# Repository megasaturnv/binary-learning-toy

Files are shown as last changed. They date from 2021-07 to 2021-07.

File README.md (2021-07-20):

# binary-learning-toy
A toy to help children and adults learn binary

### Pin connections
```
1	Switch128
0	Switch64
				
2	Switch32	A3	SegmentF
3	Switch16	A2	SegmentE
4	Switch8		A1	SegmentD
5	Switch4		A0	SegmentC
6	Switch2		13	SegmentB
7	Switch1		12	SegmentA
8	Digit1		11	Digit4
9	Digit2		10	Digit3

A4	SegmentG
A5	SegmentDP
A6	Switch Signed
A7	Switch Dec/Hex

binary switches		8
lower switches		2
digit pins		4
segment pins		8

total			22
```

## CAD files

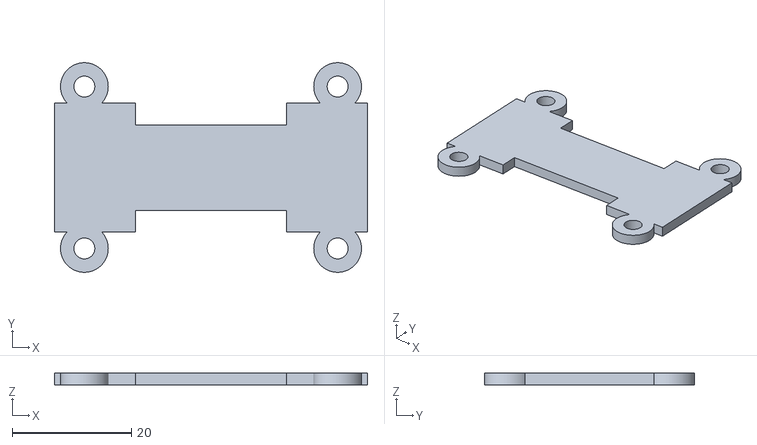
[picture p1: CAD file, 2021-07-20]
OpenSCAD/Binary_Display_Toy_DisplayLid.stl
52.4 x 35.1 x 2.00

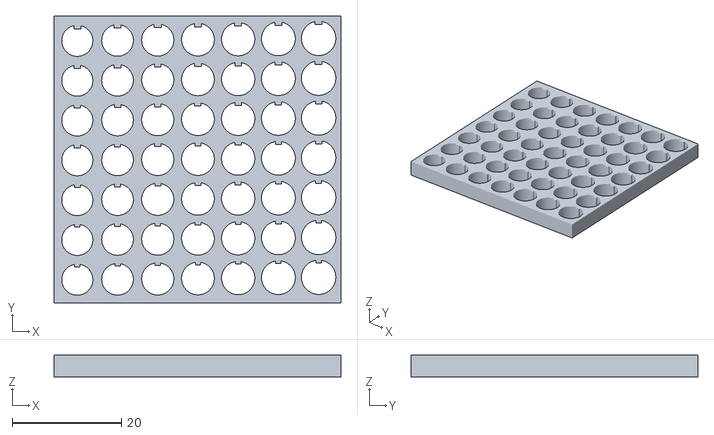
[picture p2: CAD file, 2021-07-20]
Testing/keyedSwitchHolesTest.stl
52.6 x 52.6 x 4.00

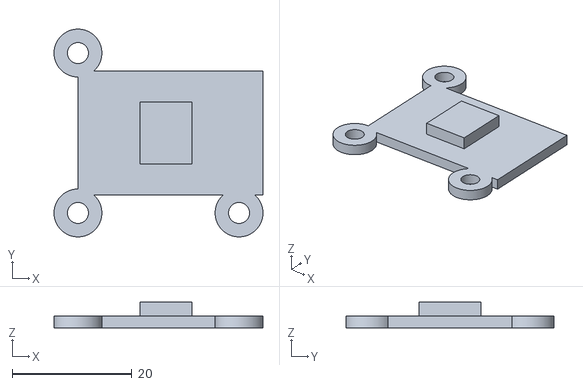
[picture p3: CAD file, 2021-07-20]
OpenSCAD/Binary_Display_Toy_ArduinoLid.stl
34.9 x 34.7 x 4.33

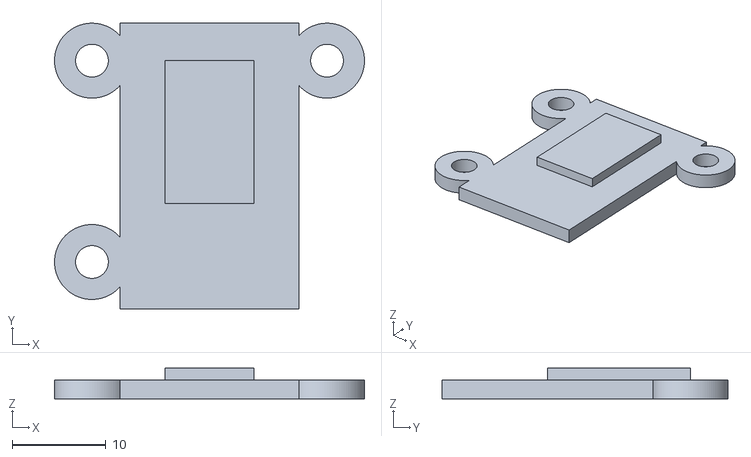
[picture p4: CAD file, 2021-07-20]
OpenSCAD/Binary_Display_Toy_BoxTP4056Lid.stl
33.1 x 30.5 x 3.30

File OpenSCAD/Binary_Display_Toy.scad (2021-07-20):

//Counting_Toy.scad by MegaSaturnv 2021-04-02
 
//TODO:
// * Replace signed and unsigned lines with variables and calculations

/////////////////////////////
// Customizable Parameters //
/////////////////////////////
/* [Basic] */
ROUNDED_EDGES      = true;

RENDER_BOX_BASE    = true;
RENDER_BOX_LID     = true;
RENDER_DISPLAY_LID = true;
RENDER_ARDUINO_LID = true;
RENDER_TP4056_LID  = true;

CURRENT_DATE = "2021-04-11";

BOX_X             = 150;
BOX_Y             = 71;
BOX_Z             = 40;
BOX_LID_Z         = 4;
BOX_LID_TOLERANCE = 0.4;
BOX_THICKNESS     = 2;

BOX_SCREW_MOUNT_DIAMETER      = 12;
BOX_SCREW_MOUNT_HOLE_DIAMETER = 3.2;
BOX_SCREW_MOUNT_HOLE_DEPTH    = 26;
BOX_SCREW_MOUNT_POSITION      = 6;

TEXT_SIZE         = 5;
TEXT_DEPTH        = 0.4;
TEXT_FONT         = "Liberation Sans:style=Bold";
TEXT_UPPER_OFFSET = 3;
TEXT_LOWER_OFFSET = 7;

DISPLAY_WIDTH      = 50.4;
DISPLAY_LENGTH     = 19.1;
DISPLAY_THICKNESS  = 8;
DISPLAY_TOP_MARGIN = 10;

SWITCH_HOLE_DIAMETER = 6.2;
SWITCH_HOLE_KEY_SIZE = 1.2;
SWITCH_POST_DIAMETER = 13;
SWITCH_POST_HEIGHT   = 7-BOX_THICKNESS;

UPPER_SWITCH_DISTANCE_BETWEEN = 9.5;
UPPER_SWITCH_QUANTITY         = 8;
UPPER_SWITCH_Y                = 50;
UPPER_SWITCH_TEXT_2           = ["1", "2", "4", "8", "16", "32", "64", "+/-"];

LOWER_SWITCH_Y = 15;
LOWER_SWITCH_X = 43;

LINES_WIDTH = 1;
LINES_DEPTH = 0.4;

18650_HOLDER_HEIGHT         = 30;
18650_TRIANGLE_EXTRA_HEIGHT = 2;
18650_HEIGHT                = 65;
18650_DIAMETER              = 18.3;
18650_SHELF_SIZE            = 8;

CIRCUITBOARDS_SCREW_MOUNT_DIAMETER      = 8; //4.7
CIRCUITBOARDS_SCREW_MOUNT_HOLE_DIAMETER = 2.5;
CIRCUITBOARDS_SCREW_MOUNT_HOLE_DEPTH    = 6;
CIRCUITBOARDS_WALL_THICKNESS            = 1;
CIRCUITBOARDS_LID_THICKNESS             = 2;

ON_OFF_SWITCH_HOLE_WIDTH  = 19.1;
ON_OFF_SWITCH_HOLE_LENGTH = 12.6;
ON_OFF_SWITCH_POS_X       = 17.4;
ON_OFF_SWITCH_POS_Z       = 20;

TP4056_WIDTH           = 17.1;
TP4056_LENGTH          = 28.5;
TP4056_THICKNESS       = 4.6;
TP4056_MOUNT_HEIGHT    = 5;
TP4056_USB_HOLE_HEIGHT = 3.0;
TP4056_USB_HOLE_WIDTH  = 8.5;
TP4056_CHARGING_LEDS_CUTOUT_POS_X  = 14.4;
TP4056_CHARGING_LEDS_CUTOUT_POS_Y  = 5.6;
TP4056_CHARGING_LEDS_CUTOUT_WIDTH  = 2;
TP4056_CHARGING_LEDS_CUTOUT_LENGTH = 6;

ARDUINO_PRO_MINI_WIDTH        = 18.7;
ARDUINO_PRO_MINI_LENGTH       = 33.9;
ARDUINO_PRO_MINI_THICKNESS    = 3.3;
ARDUINO_PRO_MINI_SCREW_HEIGHT = 2.5;

/* [Advanced] */
//Use $fn = 24 if it's a preview. $fn = 96 for the render. Increase 96 to produce a smoother curve.
$fn = $preview ? 24 : 96;


/////////////
// Modules //
/////////////
// https://www.thingiverse.com/thing:58478
// Rounded primitives for openscad
// (c) 2013 Wouter Robers 
module rcube(Size=[20,20,20],b=2)
{hull(){for(x=[-(Size[0]/2-b),(Size[0]/2-b)]){for(y=[-(Size[1]/2-b),(Size[1]/2-b)]){for(z=[-(Size[2]/2-b),(Size[2]/2-b)]){ translate([x,y,z]) sphere(b);}}}}}

module rcubeSlice(Size=[20,20,20],b=2) {
	translate([0, 0, -b])
	difference() {
		rcube([Size[0], Size[1], Size[2]+b*2], b);
	}
	cube([Size[0], Size[1], b]);
	translate([0, 0, Size[2]]) cube([Size[0], Size[1], b]);	
}

module roundedCorner(sideLength=8, thickness=2, cylinderCenter=false) {
	difference() {
		cube([sideLength, sideLength, thickness]);
		if (cylinderCenter) { //Cylinder cutout is in the centre
			translate([0, 0, -0.01]) cylinder(r=sideLength, h=thickness+0.02);
		} else { //Corner of the object is in the centre
			translate([sideLength, sideLength, -0.01]) cylinder(r=sideLength, h=thickness+0.02);
		}
	}
}

module drawAvatar(pxSize=2, thickness=2, center=true) {
    avatar = [
    " X X ",
    "XX XX",
    " XXX ",
    "  X  ",
    "X X X"];
    for (i = [0 : len(avatar)-1], j = [0 : len(avatar[i])-1]) {
        if (avatar[i][j] == "X") {
			if (center)	{
				translate([-(len(avatar)*pxSize)/2, -(len(avatar[0])*pxSize)/2, 0])
				translate([i*pxSize, j*pxSize, 0])
				cube([pxSize, pxSize, thickness]);
			} else {
				translate([i*pxSize, j*pxSize, 0])
				cube([pxSize, pxSize, thickness]);
			}
        }
    }
}

module switchHolePostOld(holeDiameter=6, postDiameter=12, keySize=1, height=2) {
	difference() {
		cylinder(d=postDiameter, h=height);
		difference() {
			translate([0, 0, -0.01]) cylinder(d=holeDiameter, h=height+0.02);
			translate([keySize/-2, holeDiameter/2 - keySize/2, -0.01]) cube([keySize, keySize, height+0.02]);
		}
	}
}
module switchHolePost(holeDiameter=6, postDiameter=12, keySize=1, height=2, justHole=false) {
	if (justHole) {
		difference() {
			cylinder(d=holeDiameter, h=height);
			translate([keySize/-2, holeDiameter/2 - keySize/2, -0.01]) cube([keySize, keySize, height+0.02]);
		}
	} else {
		difference() {
			cylinder(d=postDiameter, h=height);
			translate([0, 0, -0.01]) cylinder(d=holeDiameter, h=height+0.02);
		}
		translate([keySize/-2, holeDiameter/2 - keySize/2, 0]) cube([keySize, keySize, height]);
	}
}

module screwMountingPosts(width=50, length=30, screwHoleHeight=5, screwHoleOuterDiameter=6, screwHoleInnerDiameter=3, screwHoleInnerDepth=3, center=true, justHole=false) {
	if (center) {
		for (i=[-1,1], j=[-1,1]) {
			translate([i*(width/2), j*(length/2), 0]) difference() {
				if (!justHole) cylinder(d=screwHoleOuterDiameter, h=screwHoleHeight);
				translate([0,0,screwHoleHeight-screwHoleInnerDepth]) cylinder(d=screwHoleInnerDiameter, h=screwHoleInnerDepth+0.01);
			}
		}
	} else {
		for (i=[0,2], j=[0,2]) {
			translate([i*(width/2), j*(length/2), 0]) difference() {
				if (!justHole) cylinder(d=screwHoleOuterDiameter, h=screwHoleHeight);
				translate([0,0,screwHoleHeight-screwHoleInnerDepth]) cylinder(d=screwHoleInnerDiameter, h=screwHoleInnerDepth+0.01);
			}
		}
	}
}

module screwMount(height, diameter, holeDepth, holeDiameter, JustHole=false) {
	difference() {
		if (!JustHole) {
			cylinder(h=height, r=diameter/2);
		}
		translate([0, 0, height-holeDepth]) cylinder(h=holeDepth+0.01, r=holeDiameter/2);
	}
}

module triangle(XLength=5, YLength=8, thickness=2) {
    linear_extrude(height=thickness)
    {
        polygon(points=[[0,0],[XLength,0],[0,YLength]], paths=[[0,1,2]]);
    }
}

module holder18650(height=25, center=false, diameter18650=18, height18650=65, triangleExtraHeight=3.5) {
	if (center) {
		translate([-height18650/2, 0, 0])
		difference() {
			union() {
				//Main Block
				translate([-3, -diameter18650, -height]) cube([height18650+6, diameter18650 + 2, height-diameter18650/2]);
				//End caps
				//translate([-3, -diameter18650, -diameter18650]) cube([2, diameter18650, diameter18650]);
				//translate([height18650 + 1, -diameter18650, -diameter18650]) cube([2, diameter18650, diameter18650]);
			}
			translate([-1, -diameter18650/2, -diameter18650/2]) rotate([0, 90, 0]) cylinder(d=diameter18650, h=height18650+2);
			translate([height18650 + 3 + 0.01, -diameter18650-0.01, -height-0.01]) rotate([0, 270, 0]) triangle(height - diameter18650 + triangleExtraHeight + 0.01, diameter18650 + 0.01, height18650 + 6 + 0.02);
			translate([18650_SHELF_SIZE, -diameter18650-0.01, -height-0.01]) cube([height18650 - 2*18650_SHELF_SIZE, diameter18650+2.02, height+0.01]);
		}
	} else {
		translate([3, 0, 0])
		difference() {
			union() {
				//Main Block
				translate([-3, -diameter18650, -height]) cube([height18650+6, diameter18650 + 2, height-diameter18650/2]);
				//End caps
				//translate([-3, -diameter18650, -diameter18650]) cube([2, diameter18650, diameter18650]);
				//translate([height18650 + 1, -diameter18650, -diameter18650]) cube([2, diameter18650, diameter18650]);
			}
			translate([-1, -diameter18650/2, -diameter18650/2]) rotate([0, 90, 0]) cylinder(d=diameter18650, h=height18650+2);
			translate([height18650 + 3 + 0.01, -diameter18650-0.01, -height-0.01]) rotate([0, 270, 0]) triangle(height - diameter18650 + triangleExtraHeight + 0.01, diameter18650 + 0.01, height18650 + 6 + 0.02);
			translate([4, -diameter18650-0.01, -height-0.01]) cube([height18650-8 , diameter18650+2.02, height+0.01]);
		}
	}
}

module holder18650UpperHalf(center=false, diameter18650=18, height18650=65) {
	if (center) {
		translate([-height18650/2, 0, 0])
		difference() {
			translate([0, -diameter18650, -diameter18650/2]) cube([height18650, diameter18650, diameter18650/2]);
			translate([-0.01, -diameter18650/2, -diameter18650/2]) rotate([0, 90, 0]) cylinder(d=diameter18650, h=height18650+0.02);
		}
	} else {
		translate([3, 0, 0])
		difference() {
			translate([0, -diameter18650, -diameter18650/2]) cube([height18650, diameter18650, diameter18650/2]);
			translate([-0.01, -diameter18650/2, -diameter18650/2]) rotate([0, 90, 0]) cylinder(d=diameter18650, h=height18650+0.02);
		}
	}
}
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

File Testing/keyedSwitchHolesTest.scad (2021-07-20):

// By MegaSaturnv

/////////////////////////////
// Customizable Parameters //
/////////////////////////////
/* [Basic] */
HOLE_HEIGHT = 4;
HOLE_X_SPACING = 7.3;
HOLE_Y_SPACING = 7.3;

switchHolesSizes = [5.7,  5.8,  5.9,  6.0,  6.1,  6.2,  6.3];  // 6.1 is best
keySizes         = [1.00, 1.05, 1.10, 1.15, 1.20, 1.25, 1.30]; // 1.2 is best

/* [Advanced] */
//Use $fn = 24 if it's a preview. $fn = 96 for the render. Increase 96 to produce a smoother curve.
$fn = $preview ? 24 : 96;

////////////////
// Main Model //
////////////////
difference() {
	cube([len(switchHolesSizes) * HOLE_X_SPACING + 0.25*switchHolesSizes[round(len(switchHolesSizes)/2)], len(keySizes) * HOLE_Y_SPACING + 0.25*switchHolesSizes[round(len(switchHolesSizes)/2)], HOLE_HEIGHT]);
	for (diameterInc = [0:len(switchHolesSizes)-1], keyInc = [0:len(keySizes)-1]) {
		translate([diameterInc * HOLE_X_SPACING + 0.75*switchHolesSizes[diameterInc], keyInc * HOLE_Y_SPACING + 0.75*switchHolesSizes[diameterInc], -0.01]) difference() {
			cylinder(d=switchHolesSizes[diameterInc], h=HOLE_HEIGHT+0.02);
			translate([keySizes[keyInc]/-2, switchHolesSizes[diameterInc]/2 - keySizes[keyInc]/2, 0]) cube([keySizes[keyInc], keySizes[keyInc], HOLE_HEIGHT+0.02]);
		}
	}
}

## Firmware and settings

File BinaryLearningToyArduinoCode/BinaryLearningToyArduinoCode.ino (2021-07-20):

// TODO:
// Fix bug with 16-bit mode showing negative numbers
// Write code to make it show battery level in %
// Show battery level in % on startup
// Add a secret which shows the last 4 digits of millis()
// Add a secret for a simple AND/OR calculator. A change of signed switch saves the first number and selects enter next number. Position of signed switch selects AND/OR (could show AND/OR on screen until a bit is changed). Answer is displayed after toggling DEC/HEX, in either DEC/HEX depending on switch pos
// check values of SEG_A, SEG_B, SEG_C etc. Probably just 1,2,4,8...
// Replace if else if else if else if with switch case

////////////////////
// Basic Settings //
////////////////////
// Use 'true' if you'd like to keep any leading zeros
#define LEADING_ZEROS false

// Set brightness of display between 0 and 100
#define BRIGHTNESS 100


//////////////////
// Defined Pins //
//////////////////
#define SWITCH_128 1
#define SWITCH_64  0
#define SWITCH_32  2
#define SWITCH_16  3
#define SWITCH_8   4
#define SWITCH_4   5
#define SWITCH_2   6
#define SWITCH_1   7

#define DIGIT_1    8
#define DIGIT_2    9
#define DIGIT_3    10
#define DIGIT_4    11

#define SEGMENT_A  12
#define SEGMENT_B  13
#define SEGMENT_C  14 // A0
#define SEGMENT_D  15 // A1
#define SEGMENT_E  16 // A2
#define SEGMENT_F  17 // A3
#define SEGMENT_G  18 // A4
#define SEGMENT_DP 19 // A5

#define SWITCH_SIGNED 20  // A6
#define SWITCH_DEC_HEX 21 // A7




//////////////////////
// Global Variables //
//////////////////////
#include <SevSeg.h>
SevSeg sevseg; // Instantiate a seven segment object

byte switchesPins[] = {SWITCH_128, SWITCH_64, SWITCH_32, SWITCH_16, SWITCH_8, SWITCH_4, SWITCH_2, SWITCH_1};
byte digitPins[] = {DIGIT_1, DIGIT_2, DIGIT_3, DIGIT_4};
byte segmentPins[] = {SEGMENT_A, SEGMENT_B, SEGMENT_C, SEGMENT_D, SEGMENT_E, SEGMENT_F, SEGMENT_G, SEGMENT_DP};

String customText = " custom ";

bool slowmode = false;

///////////////
// Functions //
///////////////
int readSwitches() {
  uint8_t number = 0;

  // Read in the bits
  for (byte i = 0; i < sizeof(switchesPins); i++) {
    bitWrite(number, 7 - i, !digitalRead(switchesPins[i]));
  }

  if (digitalReadA6A7(SWITCH_SIGNED)) {
    // Read in 8 switches as an unsigned binary number
    return int(number);
  } else {
    // Convert unsigned number to a signed number
    return int(int8_t(number));
  }

}

byte readSwitchesUnsigned() {
  byte number = 0;

  // Read in the bits
  for (byte i = 0; i < sizeof(switchesPins); i++) {
    bitWrite(number, 7 - i, !digitalRead(switchesPins[i]));
  }
  return number;
}

//byte segmentStatusByte = 0;
//for (int i = 0; i < 8; i++) {
//  segmentStatusByte += (segmentStatus[i] << (7 - i));
//}

byte readSwitchesByte() {
  byte number = 0;

  // Read in the bits
  for (byte i = 0; i < sizeof(switchesPins); i++) {
    bitWrite(number, 7 - i, !digitalRead(switchesPins[i]));
  }
  return number;
}

bool digitalReadA6A7(byte pin) {
  //A6 and A7 are analogue-only so need special treatment:
  if (analogRead(pin) < 100) {
    return false;
  } else {
    return true;
  }
}

void refreshDisplayForTime(unsigned int argDuration) {
  unsigned long startTime = millis();
  while (millis() < startTime + argDuration ) {
    sevseg.refreshDisplay();
  }
}

void display16BitNumberForever() {
  byte byte16BitNumberLower = 0;
  byte byte16BitNumberUpper = 0;
  unsigned int numberToDisplay = 0;
  while (true) {

    if (digitalReadA6A7(SWITCH_SIGNED)) {
      byte16BitNumberLower = readSwitchesUnsigned();
    } else {
      byte16BitNumberUpper = readSwitchesUnsigned();
    }

    if ((byte16BitNumberLower + (256 * byte16BitNumberUpper)) < 0xFFFF) {
      numberToDisplay = byte16BitNumberLower + (256 * byte16BitNumberUpper);
    } else {
      numberToDisplay = 0xFFFF; //Prevents overflow since sevseg.setNumber accepts a signed int, not unsigned
    }
    if (digitalReadA6A7(SWITCH_DEC_HEX)) {
      sevseg.setNumber(numberToDisplay); // Display number in decimal
    } else {
      sevseg.setNumber(numberToDisplay, -1, true); // Display number in hexadecimal
    }

    refreshDisplayForTime(50);
  }
}

void displayIndividualSegmentsForever() {
  // http://lenniea.github.io/LED7Seg/class_sev_seg.html
  // https://arduino.stackexchange.com/questions/71851/how-to-control-segments-with-sevseg-library

  byte segmentStatus[4] = {0x00, 0x00, 0x00, 0x00};
  while (true) {
    byte selectedSegment = 0;
    if (!digitalReadA6A7(SWITCH_DEC_HEX)) {
      selectedSegment += 1;
    }
    if (!digitalReadA6A7(SWITCH_SIGNED)) {
      selectedSegment += 2;
    }
    segmentStatus[selectedSegment] = readSwitchesByte();
    sevseg.setSegments(segmentStatus);

    //sevseg.refreshDisplay();
    refreshDisplayForTime(50);
  }
}

void displayText(String argText, unsigned int argDelay) {
  char fourCharsText[] = "erro\0"; // This text should be overwritten in the next loop, so set it to "erro" which can tell us if there's a problem

  for (byte i = 4; i <= argText.length(); i++) {
    argText.substring(i - 4, i).toCharArray(fourCharsText, 5);
    sevseg.setChars(fourCharsText);

    unsigned long startTime = millis();
    while (millis() < startTime + argDelay ) {
      sevseg.refreshDisplay();
    }
  }
}

void displayTextBackwards(String argText, unsigned int argDelay) {
  char fourCharsText[] = "erro\0"; // This text should be overwritten in the next loop, so set it to "erro" which can tell us if there's a problem

  for (byte i = argText.length(); i >= 4; i--) {
    argText.substring(i - 4, i).toCharArray(fourCharsText, 5);
    sevseg.setChars(fourCharsText);

    unsigned long startTime = millis();
    while (millis() < startTime + argDelay ) {
      sevseg.refreshDisplay();
    }
  }
}

void displayTextForever(String argText, unsigned int argDelay) {

  char fourCharsText[] = "erro\0"; // This text should be overwritten in the next loop, so set it to "erro" which can tell us if there's a problem
  byte charNum = 4;
  bool incrementDirection = true;
  while (true) {
    argText.substring(charNum - 4, charNum).toCharArray(fourCharsText, 5);
    sevseg.setChars(fourCharsText);

    unsigned long startTime = millis();
    while (millis() < startTime + argDelay ) {
      sevseg.refreshDisplay();
    }

    if (incrementDirection) {
      charNum++;
    } else {
      charNum--;
    }

    if (charNum == 4 || charNum == argText.length()) {
      incrementDirection = !incrementDirection;
    }
  }
}

void displaySecondsForever() {
  unsigned long startTime = millis();
  while (true) {
    if (digitalReadA6A7(SWITCH_DEC_HEX)) {
      // Display number in decimal
      sevseg.setNumber(long((millis() - startTime) / 1000.0));
    } else {
      // Display number in Hexadecimal
      sevseg.setNumber(long((millis() - startTime) / 1000.0), -1, true);
    }
    sevseg.refreshDisplay();
  }
}

void displayNumberSlowly(int argNumber, unsigned int argDelayBetweenSegments, unsigned int argDuration) {
  unsigned long startTime = millis();
  while (millis() < startTime + argDuration ) {
    if (digitalReadA6A7(SWITCH_DEC_HEX)) {
      // Display number in decimal
      sevseg.setNumber(argNumber);
    } else {
      // Display number in decimal
      sevseg.setNumber(argNumber, -1, true);
    }
    delay(argDelayBetweenSegments);
    sevseg.refreshDisplay();
  }
}

double GetInternalTemp(void)
{
  unsigned int wADC;
  double t;

  // The internal temperature has to be used
  // with the internal reference of 1.1V.
  // Channel 8 can not be selected with
  // the analogRead function yet.

  // Set the internal reference and mux.
  ADMUX = (_BV(REFS1) | _BV(REFS0) | _BV(MUX3));
  ADCSRA |= _BV(ADEN);  // enable the ADC

  delay(20);            // wait for voltages to become stable.

  ADCSRA |= _BV(ADSC);  // Start the ADC

  // Detect end-of-conversion
  while (bit_is_set(ADCSRA, ADSC));

  // Reading register "ADCW" takes care of how to read ADCL and ADCH.
  wADC = ADCW;

  // The offset of 324.31 could be wrong. It is just an indication.
  t = (wADC - 324.31 ) / 1.22;

  // The returned temperature is in degrees Celsius.
  return (t);
}

long readVcc() {
  long result;
  // Read 1.1V reference against AVcc
  ADMUX = _BV(REFS0) | _BV(MUX3) | _BV(MUX2) | _BV(MUX1); delay(20); // Wait for Vref to settle
  ADCSRA |= _BV(ADSC); // Convert
  while (bit_is_set(ADCSRA, ADSC));
  result = ADCL;
  result |= ADCH << 8;
  result = 1126400L / result; // Back-calculate AVcc in mV
  return result;
}

void displayVccForever() {
  while (true) {
    if (digitalReadA6A7(SWITCH_DEC_HEX)) {
      // Display number in decimal
      sevseg.setNumberF(readVcc()/1000.0, 3);
    } else {
      // Display number in Hexadecimal
      sevseg.setNumberF(readVcc()/1000.0, 3, true);
    }
    refreshDisplayForTime(500);
  }
}

void displayVccForeverPercent() {
  while (true) {
    if (digitalReadA6A7(SWITCH_DEC_HEX)) {
      // Display number in decimal
      sevseg.setNumber(readVcc()/1000);
    } else {
      // Display number in Hexadecimal
      sevseg.setNumber(readVcc()/1000, -1, true);
    }
    refreshDisplayForTime(500);
  }
}

long readTemp() {
  long result;
  // Read temperature sensor against 1.1V reference
  ADMUX = _BV(REFS1) | _BV(REFS0) | _BV(MUX3); delay(20); // Wait for Vref to settle
  ADCSRA |= _BV(ADSC); // Convert
  while (bit_is_set(ADCSRA, ADSC));
  result = ADCL;
  result |= ADCH << 8;
  result = (result - 125) * 1075;
  return result;
}

void displayTempForever() {
  while (true) {
    if (digitalReadA6A7(SWITCH_DEC_HEX)) {
      // Display number in decimal
      sevseg.setNumber(readTemp()/10000);
    } else {
      // Display number in Hexadecimal
      sevseg.setNumber(readTemp()/10000, -1, true);
    }
    refreshDisplayForTime(500);
  }
}

//////////////////
// Main Program //
//////////////////
void setup() {
  for (byte i = 0; i < sizeof(switchesPins); i++) {
    pinMode(switchesPins[i], INPUT_PULLUP);
  }

  byte numDigits = 4; // Todo: Replace with len(digitPins)
  bool resistorsOnSegments = false; // 'false' means resistors are on digit pins
  byte hardwareConfig = COMMON_CATHODE; // See README.md for options
  bool updateWithDelays = false; // Default 'false' is Recommended
  //bool disableDecPoint = true; // Use 'true' if your decimal point doesn't exist or isn't connected
  bool disableDecPoint = false;
  sevseg.begin(hardwareConfig, numDigits, digitPins, segmentPins, resistorsOnSegments,
               updateWithDelays, LEADING_ZEROS, disableDecPoint);
  sevseg.setBrightness(BRIGHTNESS);

  if (readSwitches() == 1) {
    displayText("   16-bit   ", 500);
    display16BitNumberForever();
  } else if (readSwitches() == 2) {
    displayText("   7-seg   ", 500);
    displayIndividualSegmentsForever(); // Secret sevseg control
  } else if (readSwitches() == 4) {
    displayTextForever(customText, 500); // Display customText and scroll on screen
  } else if (readSwitches() == 8) {
    displayText("   counter   ", 500);
    displaySecondsForever();
  } else if (readSwitches() == 16) {
    displayText("   delay   ", 500);
    while (true) {
      if (readSwitches() > 0) {
        displayNumberSlowly(2017, readSwitches(), 100);
      } else {
        displayNumberSlowly(2017, 0, 100);
      }
    }
  } else if (readSwitches() == 32) {
    displayText("   Voltage   ", 500);
    displayVccForever();
  } else if (readSwitches() == 64  ) {
    displayText("   Percent   ", 500);
    displayTextForever("------", 500);
    //displayVccForeverPercent();
  } else if (readSwitches() == 128  ) {
    displayText("   Tenperature   ", 500);
    displayTempForever();
  }
}

void loop() {
  if (digitalReadA6A7(SWITCH_DEC_HEX)) {
    // Display number in decimal
    sevseg.setNumber(readSwitches());
  } else {
    // Display number in Hexadecimal
    sevseg.setNumber(readSwitches(), -1, true);
  }

  refreshDisplayForTime(50);

  //unsigned long startTime = millis();
  //while (millis() < startTime + 100 ) {
  //  sevseg.refreshDisplay();
  //}
}
